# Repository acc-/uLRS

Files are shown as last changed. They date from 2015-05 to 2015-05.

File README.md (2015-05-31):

# μLRS
μLRS - micro LRS receiver, OpenLRSng compatible<br/>
RCGroups thread: http://www.rcgroups.com/forums/showthread.php?t=2371835

## License
<br />This work is licensed under a <a rel="license" href="http://creativecommons.org/licenses/by-nc-sa/4.0/">Creative Commons Attribution-NonCommercial-ShareAlike 4.0 International License</a>.

## General
μLRS boards are hardware compatible with OpenLRSng firmware for HW 8 (micro RX). Common features for μLRS boards are:
* input voltage 4-16V (max 3S lipo, 4S is too much voltage)
* PCB pads for 3.3v UART interface (RX, TX, DTR, GND) - do **NOT** try to use it with 5v uart interface
* analog RSSI output pad
* U.FL antenna connector
* RFM22b 100mW radio module
* LFCN-490 low pass filter (can be easily removed by replacing it with 1206 0R resistor)
* LC filter for radio power supply
* Atmega328P-MU microcontroller (QFN case)
* 0603 sized components - can be soldered at home (only atmega chip requires strong soldering skills)

## v2 board
Improved version of μLRS v1 with following changes:
* vias covered by soldermask (v1 has these with copper epxosed)
* removed I2C pads
* removed 3.3v pad
* removed resistors in TX/RX pads
* removed dedicated RESET pad (but still easily accessible at the most bottom-right capacitor pad)
* smaller board - 16x16mm (0.63" x 0.63"), exactly the same size as RFM22b module
* PCBs can be ordered here: https://oshpark.com/shared_projects/H6KfYEk2



## v2 BOM
* 4x 1k 0603 resistor
* 1x 10k 0603 resistor
* 2x 22p 0603 capacitor
* 4x 100nF 0603 capacitor
* 2x 1uF 0603 capacitor (on schema one is 0402, but 0603 fits perfectly and is easier to solder)
* 2x 10uF/6.3v 0603 tantalum capacitor
* 1x 47uF/16v SMD B tantalum capacitor (schema is for SMD A, but 16v SMD A cannot be found, you can use SMD-A 6.3v but then you are limited to 5v power supply)
* 1x SOT-323 Schottky diode (let it be around 200mA), for example BAT165
* 1x green 0603 led
* 1x red 0603 led
* 1x LFCN-490 filter
* 1x mcp1703cb SOT23 voltage regulator (supports max 16V)
* 1x 16MHz crystal oscillator 3525 case
* 1x 10uH 1210 inductor
* 1x Atmega328P-MU (MLF32 case) microcontroller
* 1x RFM22B-433-S2 radio module
* 1x U.FL antenna connector

## v1 board (deprecated)
μLRS v1 is a first prototype board:
* PCB dimensions: 20x18mm
* I2C interface (SDA, SCL) pads
* 3.3v pad
* RESET pad (for SPI programming)
* big 47uF tantalum capacitor for input voltage filtering
* two 10uF tantalum capacitors (one for 3.3v filtering, another one for RSSI analog output)
* can be used also as a **transmitter**
* PCBs can be ordered here: https://oshpark.com/shared_projects/nFa7UehY



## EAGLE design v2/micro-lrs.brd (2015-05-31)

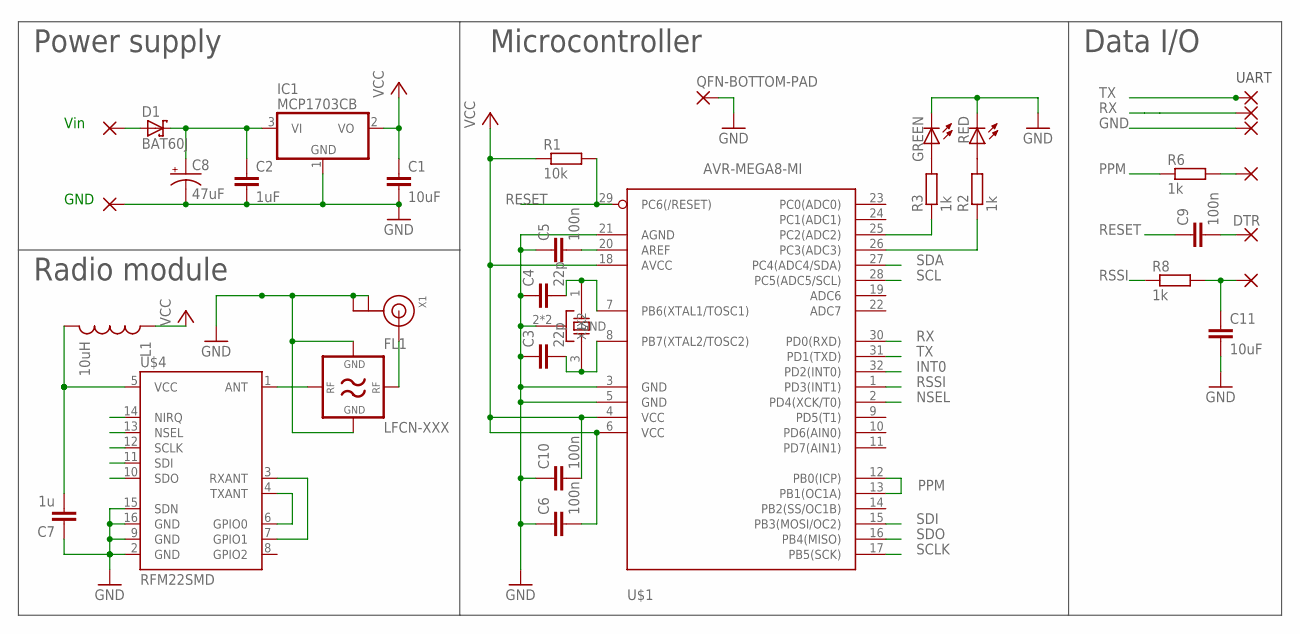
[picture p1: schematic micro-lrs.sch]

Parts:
+5V: SMD2; SMD1,27-2,54
C1, C11: 10uF; C0603
C2: 1uF; C0603
C3, C4: 22p; C0603K
C5, C6, C9, C10: 100n; C0603K
C7: 1u; C0402
C8: 47uF; EIA3216
D1: BAT60J; SOD323_ST
DTR: SMD2; SMD1,27-2,54
FL1: LFCN-XXX; FV1206
GND: SMD2; SMD1,27-2,54
IC1: MCP1703CB; SOT23
L1: 10uH; 1210
LED1: GREEN; CHIPLED_0603
LED2: RED; CHIPLED_0603
PPM: SMD2; SMD1,27-2,54
QFN-BOTTOM-PAD: QFN-PAD; SMD100X100
R1: 10k; R0603
R2, R3, R6, R8: 1k; R0603
RSSI: SMD2; SMD1,27-2,54
RX: SMD2; SMD1,27-2,54
TX: SMD2; SMD1,27-2,54
U$1: AVR-MEGA8-MI; MLF32
U$2: CTS_32X25_SMD; CTS_32X25
U$4: RFM22SMD; RFM22-XXX-S2
UART-GND: SMD2; SMD1,27-2,54
X1: ANTENNA_U.FL; U.FL

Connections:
ANT-PAD: FL1.1 (IO1), U$4.1 (ANT)
AREF: C5.2, U$1.20 (AREF)
DTR: C9.2, DTR.1
GND: C1.2, C2.2, C3.1, C4.1, C5.1, C6.1, C7.1, C8.C (-), C10.1, C11.2, FL1.3 (GND2), FL1.4 (GND1), GND.1, IC1.1 (GND), LED1.C, LED2.C, QFN-BOTTOM-PAD.P$2, U$1.3 (GND), U$1.5 (GND), U$1.21 (AGND), U$2.2 (GND), U$2.4 (GND), U$4.2 (GND), U$4.9 (GND), U$4.15 (SDN), U$4.16 (GND), UART-GND.1, X1.1 (GND), X1.2 (GND)
INT0: U$1.32 (PD2(INT0)), U$4.14 (NIRQ)
unnamed: C4.2, U$1.7 (PB6(XTAL1/TOSC1)), U$2.1 (X1)
unnamed: C3.2, U$1.8 (PB7(XTAL2/TOSC2)), U$2.3 (X2)
unnamed: R3.1, U$1.25 (PC2(ADC2))
unnamed: R2.1, U$1.26 (PC3(ADC3))
unnamed: LED1.A, R3.2
unnamed: LED2.A, R2.2
unnamed: FL1.2 (IO2), X1.3 (SIGNAL)
unnamed: U$4.4 (TXANT), U$4.6 (GPIO0)
unnamed: U$4.3 (RXANT), U$4.7 (GPIO1)
NSEL: U$1.2 (PD4(XCK/T0)), U$4.13 (NSEL)
PPM: R6.1, U$1.12 (PB0(ICP)), U$1.13 (PB1(OC1A))
PPMPAD: PPM.1, R6.2
RESET: C9.1, R1.2, U$1.29 (PC6(/RESET))
RSSI: R8.1, U$1.1 (PD3(INT1))
RSSIPAD: C11.1, R8.2, RSSI.1
RX: RX.1, U$1.30 (PD0(RXD))
SCL: U$1.28 (PC5(ADC5/SCL))
SCLK: U$1.17 (PB5(SCK)), U$4.12 (SCLK)
SDA: U$1.27 (PC4(ADC4/SDA))
SDI: U$1.15 (PB3(MOSI/OC2)), U$4.11 (SDI)
SDO: U$1.16 (PB4(MISO)), U$4.10 (SDO)
TX: TX.1, U$1.31 (PD1(TXD))
VCC: C1.1, C6.2, C10.2, IC1.2 (VO), L1.1, R1.1, U$1.4 (VCC), U$1.6 (VCC), U$1.18 (AVCC)
VCC-RADIO: C7.2, L1.2, U$4.5 (VCC)
VIN: C2.1, C8.A (+), D1.C, IC1.3 (VI)
VIN-BEFORE-DIODE: +5V.1, D1.A

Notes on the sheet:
Power supply
Data I/O
Microcontroller
Radio module
UART
Vin
GND

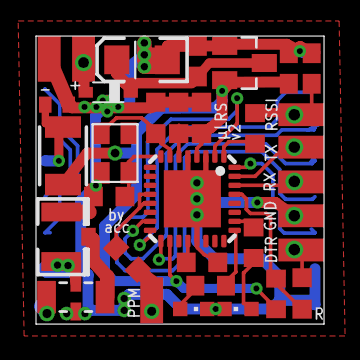
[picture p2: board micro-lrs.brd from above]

Board: 2 copper layers, 16.0 x 16.0 mm, 35 parts (1 on the bottom side), 29 nets.

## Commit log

2015-05-01 initial import
    [micro-lrs.brd, micro-lrs.sch]
2015-05-31 v2 sources
    [micro-lrs.brd, micro-lrs.sch]

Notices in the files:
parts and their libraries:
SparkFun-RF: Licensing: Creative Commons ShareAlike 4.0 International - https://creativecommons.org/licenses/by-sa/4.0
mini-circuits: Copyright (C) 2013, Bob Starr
